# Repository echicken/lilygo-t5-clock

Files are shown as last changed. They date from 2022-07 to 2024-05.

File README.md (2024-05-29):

# lilygo-t5-clock

Time, date, and weather on a LILYGO T5-4.7 ESP32 e-paper display.

Developed with Platform.IO & Arduino framework.

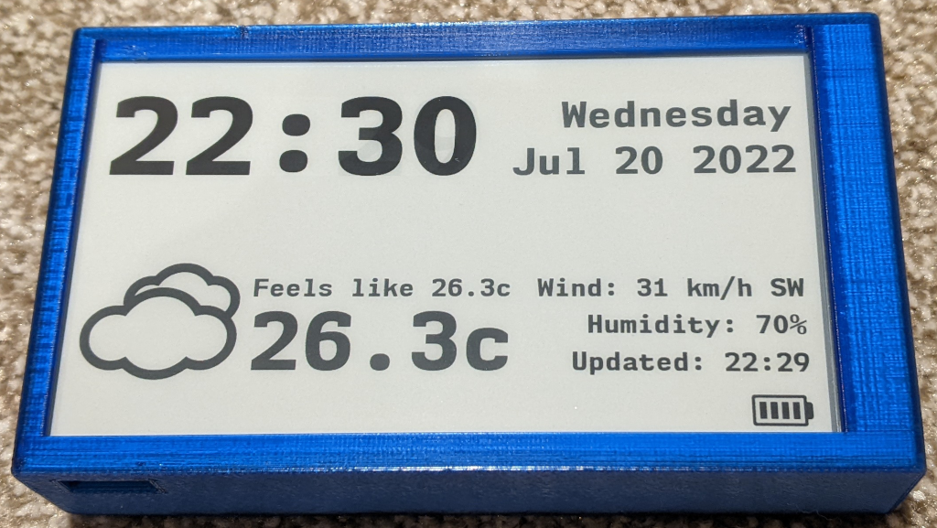
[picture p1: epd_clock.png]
A picture of the clock


## Components

- The "PH 2.0 holder" variant of [this EPD module](https://www.aliexpress.com/item/1005002006058892.html) ([manufacturer's page](http://www.lilygo.cn/prod_view.aspx?TypeId=50061&Id=1384&FId=t3:50061:3))
- [This battery](https://www.amazon.ca/gp/product/B095BTSMYH), 3.7V 10.5aH
- A JST PH 2.0 connector
- ~10cm of 22 AWG wire (for hanging)

### Battery Notes

On my EPD board, when viewing the board side, with the ESP32 module at the top-right, the positive pin of the JST PH 2.0 connector is on the left. Be careful to connect the battery to the correct pins on **your** board, which may be different from mine, and **do not** attempt to charge the battery until you're sure it's hooked up properly.

The wires on the battery that I'm using came unterminated. I just soldered the wires together with those of a pre-terminated pigtail. These are [easy to find online](https://www.amazon.ca/gp/product/B07NWD5NTN), but I just used what I had on hand and can't vouch for this exact product. Or do it the proper way with a connector and crimper, if you've got them.

## Configuration

Create a file at `src/config.h` and populate it with the following:

```c
#define WIFI_SSID "Your WiFi SSID goes here"
#define WIFI_PASS "Your WiFi password goes here"
#define OWM_KEY "Your OpenWeatherMap API key goes here"
#define OWM_LAT 43.69264
#define OWM_LON -79.38091
#define TZ_INFO "EST5EDT,M3.2.0,M11.1.0" // https://github.com/nayarsystems/posix_tz_db/blob/master/zones.csv
#define VOLTAGE_INTERVAL 1800 // Seconds between battery voltage updates
#define NTP_INTERVAL	 3600 // Seconds between NTP updates
#define WEATHER_INTERVAL 1800 // Seconds between weather updates
#define REDRAW_INTERVAL  3600 // Seconds between screen redraws
```

Customize as needed.

### Configuration Notes

Get your OpenWeatherMap API key [here](https://openweathermap.org/api).

The NTP update interval may be unnecessarily short by default. Would be worth trying different values and checking the time against a known good clock.

The display is cleared and redrawn entirely every `REDRAW_INTERVAL` seconds. Helps to get rid of ghosting and clean up the display, as parts that should be blank (white) tend to darken over time, and garbage occasionally appears in unexpected places.

## Design Notes

### Enclosure

I'm using the variant of this display with a JST battery connector, along with [this battery](https://www.amazon.ca/gp/product/B095BTSMYH). This allows for a thinner case and longer battery life than with the 18650 variant. Case STL and OpenSCAD source are in the [enclosure/](enclosure/) directory.

### Power Consumption

The EPD is fully powered off, along with the obnoxious blue LED, except when actively drawing. (The blue LED is always on when on USB power, but not on battery.)

I initially used the Arduino [Ticker](https://www.arduino.cc/reference/en/libraries/ticker/) library, and then [TickTwo](https://github.com/sstaub/TickTwo) in order to schedule various timed events. It quickly became clear that the current consumption was unsuitable for a battery-powered device, even when turning WiFi off when it wasn't needed and limiting screen updates to a reasonable extent.

#### Deep Sleep

I'm now putting the ESP32 into deep sleep mode when it can sit idle, waking it up once per minute to update the clock. (The sleep interval is recalculated each time, so that it'll update as close to the start of the next minute as possible.) In this scenario, the `loop()` function is never called, and everything happens in `setup()`. Values are stored in RTC memory to persist between sleep/wake cycles. Some good info on this topic was found [here](https://randomnerdtutorials.com/esp32-deep-sleep-arduino-ide-wake-up-sources/).

The **clock** will update every minute, on the minute (ish), but there will be some slop among the other update intervals. They'll happen as scheduled (ish) but may lag by up to a minute, causing the schedule to drift over time. Bear this in mind if you're watching and expecting to see eg. a weather update at a particular time.

##### Buttons

The leftmost button (viewing the display-side in landscape orientation), labelled S5, pulls the ESP32's RST line to ground. This restarts the device.

I've considered assigning functions to the rightmost three buttons, but the design of this device makes that a hassle when combined with deep sleep.

I've decided it's sufficient to be able to restart the device if something goes wrong. To that end I plan on leaving a hole in the enclosure so I can press the reset button with a pen or something if needed.

###### More Button Musing

The second-leftmost button is connected to the ESP32's GPIO 0, probably to put it into flash mode when pressed along with RST, but I can't remember offhand.

The remaining three buttons are active low. Their GPIOs have pull-up resistors on them. The ESP32 has two GPIO-triggered wake-up modes. The first, ext0, requires you to assign one GPIO to trigger wake-up, and will wake the device whether this goes from low to high or high to low. The second, ext1, will wake the device if one of several GPIOs goes from low to high; unfortunately all three of our available switches are already pulled up. In order to use multiple buttons, we'd need to use ext0 to wake the device, then enter an input-handling routine for some amount of time. Not difficult to do, but not worth the hassle in my opinion.

#### Clearing and redrawing

Partial updating of the screen is used for speed and, presumably, to reduce power consumption. Steps are taken to update parts of the screen only as needed. This could probably be taken a bit further by updating single characters (eg. if only the minute has changed), but I'm not sure it's worth the bother. For now, the entire hours-and-minutes field is cleared and redrawn when the time changes even by a minute, likewise the date, the temperature, and so on.

## Credits

[Dushyant Ahuja](https://github.com/dushyantahuja)'s [SimpleWeather](https://github.com/dushyantahuja/SimpleWeather) was taken and adapted for use in this project.

The [LilyGo EPD47](https://github.com/Xinyuan-LilyGO/LilyGo-EPD47) driver from [Valentin Roland](https://github.com/vroland)'s [EPDiy](https://github.com/vroland/epdiy) project via [Xinyuan-LilyGO](https://github.com/Xinyuan-LilyGO) is used in this project.

Weather icons are from the [Meteocons](https://www.alessioatzeni.com/meteocons/) font by [Alessio Atzeni](https://www.alessioatzeni.com/meteocons/). A [font conversion script](https://github.com/Xinyuan-LilyGO/LilyGo-EPD47/blob/master/scripts/fontconvert.py) is included in the [LilyGo EPD47](https://github.com/Xinyuan-LilyGO/LilyGo-EPD47) project and was used here.

The NTP client is from [here](https://github.com/arduino-libraries/NTPClient) via [Arduino Libraries](https://github.com/arduino-libraries).

Probably others that I'm forgetting, and there's a whole stack of other people's hard work beneath all of that.

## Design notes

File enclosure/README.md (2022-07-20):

# Enclosure

- [./assembled.stl](assembled.stl) is here for illustrative purposes, so you can see the assembled case. Don't print it.
- [./case.stl](case.stl) is the main body of the case, to be printed as shown with the open top facing up. No supports needed. The battery and EPD module just slide into their channels.
- [./lid.stl](lid.stl) has two posts that press fit into sockets on the case body. On my printed part, this holds the lid flat and secure and no glue or fasteners are needed. Print this with the posts and bezel strip facing up (obviously).
- [./case.scad](case.scad) is the OpenSCAD source for this design so you can tinker with parameters if needed.

I printed my case in eSun transparent Blue PETG on a Prusa i3 mk3. Your results may differ depending on your printer and material. In particular you may want to tweak the `tol` and `vwt` parameters in [./case.scad](case.scad) for best results. The `tol` parameter will affect the fit of the lid posts and lid bezel strip.

A length of 22 AWG wire is threaded through the holes on the rear of the case and twisted around itself at the ends. This is for hanging the clock on a wall hook, nail, or screw.

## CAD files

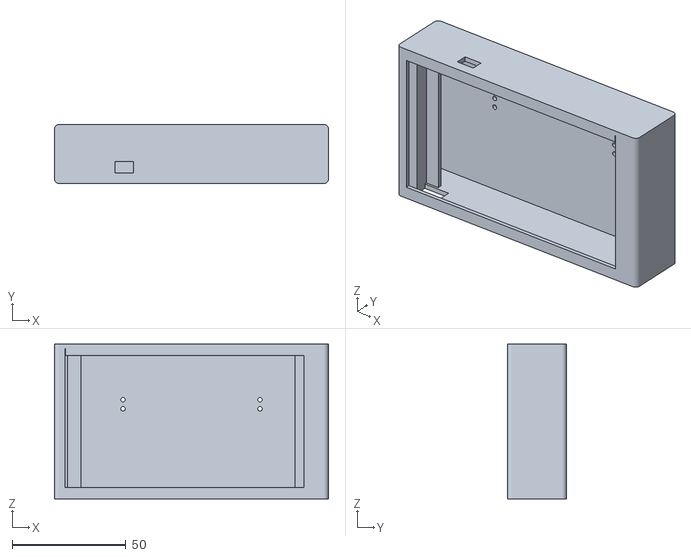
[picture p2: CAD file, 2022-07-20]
enclosure/assembled.stl
120.3 x 26.0 x 68.0

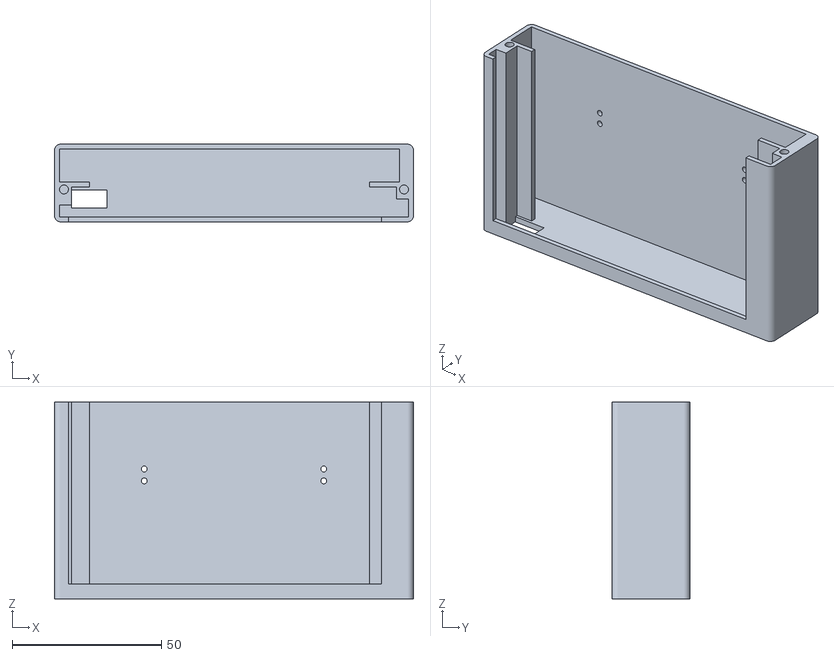
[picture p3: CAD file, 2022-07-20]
enclosure/case.stl
120.3 x 26.0 x 66.0

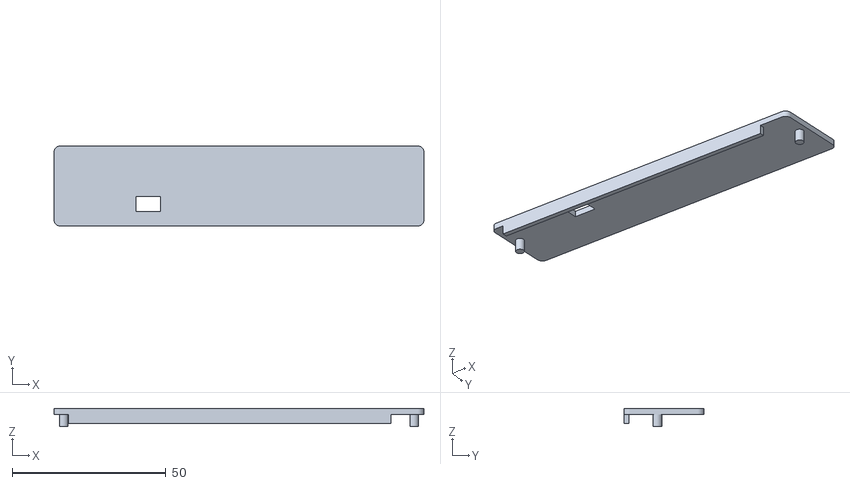
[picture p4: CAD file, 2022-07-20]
enclosure/lid.stl
120.3 x 26.0 x 6.00

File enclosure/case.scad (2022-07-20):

batt_w = 114;  // Battery width
batt_h = 61;   // Battery height
batt_t = 11;   // Battery thickness
batt_lip = 10; // Battery channel overlaps this much of the battery on each side

epd_w = 117; // Width of EPD module (board, display, tape)
epd_h = 64;  // Height of EPD module (board, display, excludes USB-C projection)
epd_tl = 4;  // Thickness of EPD module on left-hand side
epd_tr = 6;  // Thickness of EPD module on right-hand side
epd_tf = 10; // Full thickness / thickest measurement of EPD module including mounted components (exaggerated)
epd_lip = 4; // EPD module channel overlaps this much of the EPD module on each side

// USB-C measurements have been exaggerated to make it easier to plug in
usb_ol = 4;          // USB-C connector offset from left of board
usb_w = 12;          // USB-C connector width
usb_t = 6;           // USB-C connector thickness
usb_of = epd_tl - 1; // USB-C connector offset from front

disp_or = 9; // Display-area offset from right side of EPD module
disp_ol = 3; // Display-area offset from left side of EPD module
disp_ob = 3; // Display-area offset from bottom of EPD module
disp_ot = 3; // Display-area offset from top of EPD module

vwt = 1.67;  // Vertical wall thickness
hwt = 2;     // Horizontal wall thickness
cr = 2;      // Corner radius
pd = 3;      // Post diameter (for lid press-fit)
pr = pd / 2; // Post radius
phz = 5;     // Post hole height
pz = 4;      // Post height
wd = 2;      // Hanging wire diameter

bl = 25; // Button offset from left of EPD module
bw = 8;  // Button width (exaggerated for easier access)
by = 5;  // Button hole y axis (exaggerated for easier access)

tol = .127; // Tolerance for post hole and lid bezel fit

ch = hwt + epd_h; // Case height
cw = vwt + epd_w + vwt; // Case width
ct = vwt + epd_tf + vwt + batt_t + vwt; // Case thickness

$fn = 180;

module block() {
    hull() {
        translate([cr, cr, 0]) {
            cylinder(h = ch, r = cr);
        }
        translate([cw - cr, cr, 0]) {
            cylinder(h = ch, r = cr);
        }
        translate([cr, ct - cr, 0]) {
            cylinder(h = ch, r = cr);
        }
        translate([cw - cr, ct - cr, 0]) {
            cylinder(h = ch, r = cr);
        }
    }
}

module wire_holes() {
    translate([0, ct, ch * .66]) {
        rotate([90, 0, 0]) {
            cylinder(d = wd, h = vwt * 2);
        }
        translate([0, 0, -(wd * 2)]) {
            rotate([90, 0, 0]) {
                cylinder(d = wd, h = vwt * 2);
            }
        }
    }
}

module cutouts() {
    // Display area
    translate([vwt + disp_ol, 0, hwt + disp_ob]) {
        cube([cw - (vwt * 2) - disp_ol - disp_or, vwt, ch - hwt - disp_ob]);
    }
    // EPD module left cutout
    translate([vwt, vwt, hwt]) {
        cube([epd_w / 2, epd_tl, ch]);
    }
    // EPD module right cutout
    translate([vwt + (epd_w / 2), vwt, hwt]) {
        cube([epd_w / 2, epd_tr, ch]);
    }
    // EPD lip cutout
    translate([vwt + epd_lip, vwt + epd_tl, hwt]) {
        cube([epd_w - (epd_lip * 2), epd_tr, ch]);
    }
    // Battery cutout
    translate([vwt, vwt + epd_tf + vwt, hwt]) {
        cube([batt_w, batt_t, ch]);
    }
    // Battery lip cutout
    translate([vwt + batt_lip, vwt + epd_tf, hwt]) {
        cube([batt_w - (batt_lip * 2), vwt, ch]);
    }
    // USB-C cutout
    translate([vwt + usb_ol, vwt + usb_of, 0]) {
        cube([usb_w, usb_t, hwt]);
    }
    // Lid post holes
    translate([vwt + pr, vwt + epd_tr + vwt + pr, ch - phz]) {
        cylinder(d = pd, h = phz);
    }
    translate([cw - vwt - pr, vwt + epd_tr + vwt + pr, ch - phz]) {
        cylinder(d = pd, h = phz);
    }
    // Wire hanger holes
    translate([cw * .25, 0, 0]) wire_holes();
    translate([cw * .75, 0, 0]) wire_holes();
}

module case() {
    difference() {
        block();
        cutouts();
    }
}

module lid() {
    difference() {
        union() {
            hull() {
                translate([cr, cr, 0]) {
                    cylinder(h = hwt, r = cr);
                }
                translate([cw - cr, cr, 0]) {
                    cylinder(h = hwt, r = cr);
                }
                translate([cr, ct - cr, 0]) {
                    cylinder(h = hwt, r = cr);
                }
                translate([cw - cr, ct - cr, 0]) {
                    cylinder(h = hwt, r = cr);
                }
            }
            // Bezel strip
            translate([vwt + disp_ol + (tol / 2), 0, -disp_ot]) {
                cube([cw - (vwt * 2) - disp_ol - disp_or - tol, vwt, disp_ot]);
            }
            // Lid posts
            translate([vwt + pr, vwt + epd_tr + vwt + pr, -pz]) {
                cylinder(d = pd - tol, h = pz);
            }
            translate([cw - vwt - pr, vwt + epd_tr + vwt + pr, -pz]) {
                cylinder(d = pd - tol, h = pz);
            }
        }
        // Button pokin' hole
        translate([vwt + bl, vwt + epd_tl - 1, 0]) {
            cube([bw, by, hwt]);
        }
    }
}

case();
translate([0, 0, ch]) lid();

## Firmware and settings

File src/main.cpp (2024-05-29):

#ifndef BOARD_HAS_PSRAM
#error "Please enable PSRAM !!!"
#endif

#include <Arduino.h>
#include "config.h"
#include <esp_task_wdt.h>
#include "freertos/FreeRTOS.h"
#include "freertos/task.h"
#include "epd_driver.h"
#include "NK5715b.h"
#include "NK5724b.h"
#include "NK5748b.h"
#include "NK5772b.h"
#include "Meteocons96.h"
#include "esp_adc_cal.h"
#include <Wire.h>
#include <sys/time.h>
#include "WiFi.h"
#include "WiFiUdp.h"
#include <NTPClient.h>
#include "SimpleWeather.h"
#include "batt_100.h"
#include "batt_75.h"
#include "batt_50.h"
#include "batt_25.h"
#include "batt_0.h"

#define BATT_PIN 36

#define EPD_WIDTH 960
#define EPD_HEIGHT 540
#define H_MARGIN 20
#define V_MARGIN 20

const uint CLOCK_X = H_MARGIN;
const uint CLOCK_Y = 175;
const uint DATE_X = EPD_WIDTH - H_MARGIN;
const uint DATE_Y1 = 105;
const uint DATE_Y2 = CLOCK_Y;
const uint BATT_X = EPD_WIDTH - H_MARGIN - batt_100_width;
const uint BATT_Y = EPD_HEIGHT - V_MARGIN - batt_100_height;
const uint START_TIME_X = EPD_WIDTH - H_MARGIN;
const uint START_TIME_Y = EPD_HEIGHT - V_MARGIN;
const uint WICON_X = H_MARGIN;
const uint WICON_Y = 450;
const uint CTEMP_X = 235;
const uint CTEMP_Y = 450;
const uint FTEMP_X = 235;
const uint FTEMP_Y = 350;
const uint WIND_X = EPD_WIDTH - H_MARGIN;
const uint WIND_Y = 350;
const uint HUMID_X = WIND_X;
const uint HUMID_Y = 400;
const uint WUPDATE_X = WIND_X;
const uint WUPDATE_Y = 450;

/**
 * WICON_AREA is used when erasing the weather icon prior to redrawing.
 * I may have messed up when generating the Meteocons font, or it may just be
 * that it's an unusual font. Either way, the clearString function wasn't
 * consistently erasing the entire previous icon. Here we'll just define a
 * large area that definitely eoncompasses the whole thing.
 */
const Rect_t WICON_AREA = {
	.x = H_MARGIN,
	.y = (int32_t)(EPD_HEIGHT / 2) - 10,
	.width = (int32_t)(CTEMP_X - H_MARGIN - 5),
	.height = (int32_t)(BATT_Y - (EPD_HEIGHT / 2) + 10),
};

const Rect_t BATT_AREA = {
	.x = BATT_X,
	.y = BATT_Y,
	.width = batt_100_width,
	.height = batt_100_height,
};

bool _drawDate = false;
bool _drawWeather = false;
bool _drawWicon = false;
bool _drawTemp = false;
bool _drawFtemp = false;
bool _drawWind = false;
bool _drawHumidity = false;
bool _drawVoltage = false;
char _tod[10];
char _dow[20];
char _mdy[50];
char _wIcon[5];
char _wTemp[10];
char _wFeels[20];
char _wWind[25];
char _wHumidity[20];
char _wUpdated[20];
uint8_t _batt = 0;
time_t waketime;
enum alignment { LEFT, RIGHT, CENTER };

RTC_DATA_ATTR bool firstRun = true;
RTC_DATA_ATTR int minute = -1;
RTC_DATA_ATTR int dayOfWeek = -1;
RTC_DATA_ATTR int vref = 1100;
RTC_DATA_ATTR int batt = 5;
RTC_DATA_ATTR float voltage = -1;
RTC_DATA_ATTR char tod[10];
RTC_DATA_ATTR char dow[20];
RTC_DATA_ATTR char mdy[50];
RTC_DATA_ATTR char wIcon[5];
RTC_DATA_ATTR char wTemp[10];
RTC_DATA_ATTR char wFeels[20];
RTC_DATA_ATTR char wWind[25];
RTC_DATA_ATTR char wHumidity[20];
RTC_DATA_ATTR char wUpdated[20];
RTC_DATA_ATTR time_t lastNtpUpdate;
RTC_DATA_ATTR time_t lastVoltageUpdate;
RTC_DATA_ATTR time_t lastWeatherUpdate;
RTC_DATA_ATTR time_t lastRedraw;

WiFiUDP ntpUDP;
NTPClient timeClient(ntpUDP);
GFXfont currentFont;
weatherData w;
OpenWeather weather(OWM_KEY, OWM_LAT, OWM_LON);

int setUnixtime(int32_t unixtime) {
	timeval epoch = {unixtime, 0};
	return settimeofday((const timeval*)&epoch, 0);
}

void setFont(GFXfont const &font) {
	currentFont = font;
}

void clearString(int x, int y, String text, alignment align) {
	char *data  = const_cast<char*>(text.c_str());
	int x1, y1;
	int w, h;
	int xx = x, yy = y;
	get_text_bounds(&currentFont, data, &xx, &yy, &x1, &y1, &w, &h, NULL);
	if (align == RIGHT)  x = x - w;
	if (align == CENTER) x = x - w / 2;
	Rect_t area = {
		.x = x,
		.y = y - h,
		.width = w,
		.height = h,
	};
	epd_clear_area(area);
}

void drawString(int x, int y, String text, alignment align) {
	char *data  = const_cast<char*>(text.c_str());
	int x1, y1;
	int w, h;
	int xx = x, yy = y;
	get_text_bounds(&currentFont, data, &xx, &yy, &x1, &y1, &w, &h, NULL);
	if (align == RIGHT)  x = x - w;
	if (align == CENTER) x = x - w / 2;
	writeln((GFXfont *)&currentFont, data, &x, &y, NULL);
}

void drawString(int x, int y, String text, String old_text, alignment align) {
	if (!firstRun) {
		clearString(x, y, old_text, align);
	}
	drawString(x, y, text, align);
}

void redrawClock() {
	setFont(NK5772B);	
	drawString(CLOCK_X, CLOCK_Y, tod, LEFT);
	setFont(NK5724B);
	drawString(DATE_X, DATE_Y1, dow, RIGHT);
	drawString(DATE_X, DATE_Y2, mdy, RIGHT);
}

void drawClock() {
	setFont(NK5772B);
	drawString(CLOCK_X, CLOCK_Y, _tod, tod, LEFT);
	if (_drawDate) {
		setFont(NK5724B);
		drawString(DATE_X, DATE_Y1, _dow, dow, RIGHT);
		drawString(DATE_X, DATE_Y2, _mdy, mdy, RIGHT);
	}
}

void getClock() {
	struct tm now;
	getLocalTime(&now);
	strftime(_tod, 10, "%H:%M", &now);
	if (dayOfWeek != now.tm_wday) {
		_drawDate = true;
		dayOfWeek = now.tm_wday;
		strftime(_dow, 20, "%A", &now);
		strftime(_mdy, 50, "%b %d %Y", &now);
	}
}

void setClock() {
	strcpy(tod, _tod);
	if (_drawDate) {
		strcpy(dow, _dow);
		strcpy(mdy, _mdy);
	}
}

void getVoltage() {
	// Correct the ADC reference voltage
	esp_adc_cal_characteristics_t adc_chars;
	esp_adc_cal_value_t val_type = esp_adc_cal_characterize(ADC_UNIT_1, ADC_ATTEN_DB_11, ADC_WIDTH_BIT_12, 1100, &adc_chars);
	if (val_type == ESP_ADC_CAL_VAL_EFUSE_VREF) vref = adc_chars.vref;
	delay(10); // Make adc measurement more accurate
	uint16_t v = analogRead(BATT_PIN);
	float _voltage = ((float)v / 4095.0) * 2.0 * 3.3 * (vref / 1000.0);
	if (_voltage != voltage) {
		voltage = _voltage;
		// These values were arrived at via careful reasoning and due consideration, I assure you. I absolutely did not just make them up.
		if (voltage < 3.7) {
			_batt = 0;
		} else if (voltage < 3.8) {
			_batt = 1;
		} else if (voltage < 3.9) {
			_batt = 2;
		} else if (voltage < 4) {
			_batt = 3;
		} else {
			_batt = 4;
		}
		if (batt != _batt) {
			batt = _batt;
			_drawVoltage = true;
		}
	}
	time(&lastVoltageUpdate);
}

void redrawVoltage() {
	if (batt == 0) {
		epd_draw_grayscale_image(BATT_AREA, (uint8_t *)batt_0_data);
	} else if (batt == 1) {
		epd_draw_grayscale_image(BATT_AREA, (uint8_t *)batt_25_data);
	} else if (batt == 2) {
		epd_draw_grayscale_image(BATT_AREA, (uint8_t *)batt_50_data);
	} else if (batt == 3) {
		epd_draw_grayscale_image(BATT_AREA, (uint8_t *)batt_75_data);
	} else {
		epd_draw_grayscale_image(BATT_AREA, (uint8_t *)batt_100_data);
	}
}

void drawVoltage() {
	epd_clear_area(BATT_AREA);
	redrawVoltage();
}

void enableWifi() {
    WiFi.mode(WIFI_STA);
    WiFi.disconnect();
    delay(100);
    WiFi.begin(WIFI_SSID, WIFI_PASS);
	while (WiFi.status() != WL_CONNECTED) {
		delay(1000);
    }
}

void disableWifi() {
	WiFi.disconnect();
	WiFi.mode(WIFI_OFF);
}

void ntpUpdate() {

	enableWifi();
	timeClient.begin();
	bool updated = timeClient.update();
	timeClient.end();
	disableWifi();

	if (updated) setUnixtime(timeClient.getEpochTime());

	time(&lastNtpUpdate);

}

void redrawWeather() {
	setFont(Meteocons96);
	drawString(WICON_X, WICON_Y, wIcon, LEFT);
	setFont(NK5748B);
	drawString(CTEMP_X, CTEMP_Y, wTemp, LEFT);
	setFont(NK5715B);
	drawString(FTEMP_X, FTEMP_Y, wFeels, LEFT);
	drawString(WIND_X, WIND_Y, wWind, RIGHT);
	drawString(HUMID_X, HUMID_Y, wHumidity, RIGHT);
	drawString(WUPDATE_X, WUPDATE_Y, wUpdated, RIGHT);
}

void drawWeather() {

	setFont(Meteocons96);
	if (_drawWicon) {
		epd_clear_area(WICON_AREA);
		drawString(WICON_X, WICON_Y, wIcon, LEFT);
	}

	setFont(NK5748B);

	if (_drawTemp) {
		drawString(CTEMP_X, CTEMP_Y, _wTemp, wTemp, LEFT);
	}

	setFont(NK5715B);

	if (_drawFtemp) {
		drawString(FTEMP_X, FTEMP_Y, _wFeels, wFeels, LEFT);
	}

	if (_drawWind) {
		drawString(WIND_X, WIND_Y, _wWind, wWind, RIGHT);
	}

	if (_drawHumidity) {
		drawString(HUMID_X, HUMID_Y, _wHumidity, wHumidity, RIGHT);
	}

	drawString(WUPDATE_X, WUPDATE_Y, _wUpdated, wUpdated, RIGHT);

}

void getWeather() {

	enableWifi();
	bool updated = weather.updateStatus(&w);
	disableWifi();

	time(&lastWeatherUpdate);
	struct tm now;
	getLocalTime(&now);

	if (updated) {

		_drawWeather = true;

		sprintf(_wIcon, "%s", weather.getIcon(w.icon));
		if (wIcon != _wIcon) _drawWicon = true;

		sprintf(_wTemp, "%.1fc", w.current_Temp);
		if (strcmp(wTemp, _wTemp) != 0) _drawTemp = true;

		sprintf(_wFeels, "Feels like %.1fc", w.feels_like);
		if (strcmp(wFeels, _wFeels) != 0) _drawFtemp = true;

		int ws = w.wind_speed * 3.6;
		String wd = weather.getWindDirection(w.wind_direction);
		sprintf(_wWind, "Wind: %d km/h %s", ws, wd);
		if (strcmp(wWind, _wWind) != 0) _drawWind = true;

		sprintf(_wHumidity, "Humidity: %d%%", w.humidity);
		if (strcmp(wHumidity, _wHumidity) != 0) _drawHumidity = true;

		strftime(_wUpdated, 20, "Updated: %H:%M", &now);

	} else {

		strftime(_wUpdated, 20, "! Updated: %H:%M", &now);

	}
	
}

void setWeather() {
	if (_drawWicon) strcpy(wIcon, _wIcon);
	if (_drawTemp) strcpy(wTemp, _wTemp);
	if (_drawFtemp) strcpy(wFeels, _wFeels);
	if (_drawWind) strcpy(wWind, _wWind);
	if (_drawHumidity) strcpy(wHumidity, _wHumidity);
	strcpy(wUpdated, _wUpdated);
}

void redraw() {
	epd_init();
	epd_poweron();
	epd_clear();
	redrawClock();
	redrawWeather();
	if (firstRun) getVoltage();
	redrawVoltage();
	epd_poweroff_all();
	time(&lastRedraw);
}

void partialRedraw() {
	epd_init();
	epd_poweron();
	drawClock();
	if (_drawWeather) drawWeather();
	if (waketime - lastVoltageUpdate >= VOLTAGE_INTERVAL) {
		getVoltage();
		if (_drawVoltage) drawVoltage();
	}
	epd_poweroff_all();
}

void setup() {

	setenv("TZ", TZ_INFO, 1);
	tzset(); // Assign the local timezone from setenv
	disableCore0WDT(); // Network requests may block long enough to trigger watchdog

	if (firstRun) {
		ntpUpdate();
		time(&waketime);
		getClock();
		setClock();
		getWeather();
		setWeather();
		redraw();
		firstRun = false;
	} else {
		time(&waketime);
		bool r = waketime - lastRedraw >= REDRAW_INTERVAL;
		if (waketime - lastNtpUpdate >= NTP_INTERVAL) {
			ntpUpdate();
			time(&waketime);
		}
		if (waketime - lastWeatherUpdate >= WEATHER_INTERVAL) getWeather();
		getClock();
		if (!r) partialRedraw();
		setClock();
		if (_drawWeather) setWeather();
		if (r) redraw();
	}

	int nextRun = (60 - (waketime % 60));
	if (nextRun < 5) nextRun += 5;

	esp_sleep_enable_timer_wakeup(nextRun  * 1000000);
	esp_deep_sleep_start();

}

void loop() {

}

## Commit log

2022-07-15 Font conversion & EPD+LED poweroff.
2022-07-15 Ditched the firstRun variable, seemed like a good idea at the time and turned out to be more hassle. May reconsider later. Requires several checks for empty strings etc. now. :|
    Only recalculate vref during updateVoltage, no need to do that in
    every setup() run. (Wasn't a problem prior to deep sleep.)
    Misc. small reorganizations.
    [main.cpp]
2022-07-15 Notes re: buttons and why they don't do nothin' right now.
2022-07-15 Button notes.
2022-07-15 Battery notes.
2022-07-16 Simplified and streamlined drawWeather() a bit, also fixing a bug where existing weather data was not displayed upon periodic full screen redraw (weatherData w does not persist across sleep/wake; cou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
    [main.cpp]
2022-07-17 Removed periodic redraw, seems unnecessary. May reconsider.
    Reorganized things in an effort to power on the EPD as briefly as
    possible. Only drawing functions are called while the EPD is on;
    all of the updating stuff runs before the display is powered on,
    and remaining housekeeping is done after it's powered off.
    Voltage display is broken (0.00V) when on battery power, at least
    upon startup (next updating pending here). Worked when USB was
    connected; maybe the EPD needs to be powered on before we can
    read this value. Will fix later.
    [main.cpp]
2022-07-17 Folded getVoltage/setVoltage into drawVoltage().
    Apparently we can't read the voltage when on battery power unless
    the EPD is on, so I've moved things around to accommodate.
2022-07-18 Avoid unnecessary work if weather update fails.
    Don't update the displayed weather updated time string in this
    case either, since that's misleading.
    [main.cpp]
2022-07-18 Battery icons
2022-07-18 Added battery level icons.
    Removed voltage display.
    Removed startup time display.
    Reduced the size of the weather icon clearing rect.
2022-07-20 Solved (?) erratic redraw / update behaviour.
    Redraw was leaving some areas blank at times. Updates were
    occurring off schedule in other cases. My guess is that something
    else is using the obscure variable name "updates", causing this
    thing to think it needed to update stuff when it shouldn't. Who
    knew.
    [main.cpp]
2022-07-20 Enclosure STL and OpenSCAD source
    [assembled.stl, case.scad, case.stl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]
2022-07-20 Battery notes
2022-07-20 Enclosure path
2022-07-20 Moved battery icons to lib/icons/.
2022-07-20 Notes on the enclosure.
2022-07-20 Wire hanger notes.
2022-07-20 Fixed wonky date redraw. More work pending to fix weather & battery indicator redraws.
    [main.cpp]
2022-07-21 Updated image with enclosure and current display layout.
2022-07-21 Correct little whoopsie with waketime that was preventing redraw and ntp update. Logging stuff to be removed later.
    [main.cpp]
